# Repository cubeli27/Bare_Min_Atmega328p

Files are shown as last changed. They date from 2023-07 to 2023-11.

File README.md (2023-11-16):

# Bare_Min_Atmega328p
PCB designed for available in-house parts. With my main goal to test the procces of ordering from a fab house, see the outcome, as well as lab capabilities with relatively tiny components, and USB to UART.

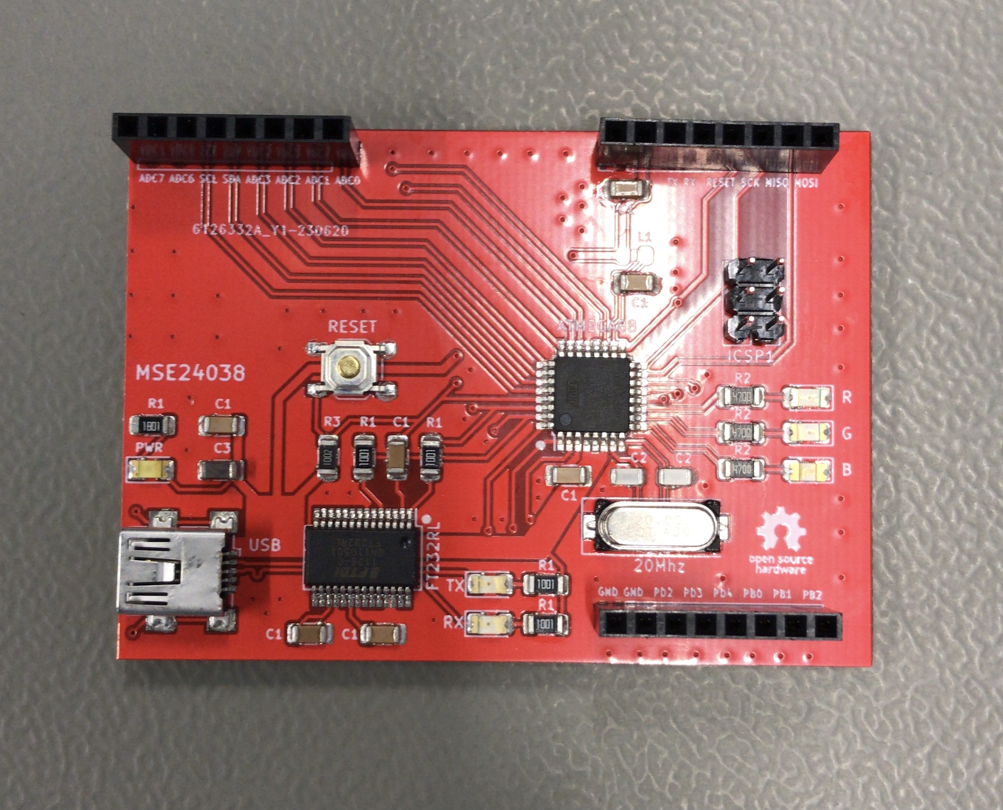
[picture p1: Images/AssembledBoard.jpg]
Assembled Board


# Assembly

Silkscreen is simplified for hand assembly hence the minimum amount of different values and the same names for many parts;
 ```ignore
 | Resistor |  Capacitor   | Inductor    |    LED                  |
 |----------|--------------|-------------|-------------------------|
 | R1 = 1k  | C1 = 100nF   |  L1 = 10uH  | PWR = White             |
 | R2 = 470 | C2 = 22pF    |             | R/G/B = Red/Green/Blue  |
 | R3 = 10k | C3 = 10uF    |             | RX/TX = Orange          |

 ```

Tip: 
R1 next to the PWR led should be more than 1k unless you want it to always be too bright, I recommend 1k8 or 2k2.

# Programming
1. Open in Arduino IDE File/Examples/11.ArduinoISP/ArduinoISP.
2. Uncomment line 81 (// #define USE_OLD_STYLE_WIRING).

UncommentLine

3. Upload the code to your Arduino Uno with Board: Arduino Uno, Programmer: AVRISP mkII.
4. Connect Arduino Uno with the custom board like so:
 ```ignore
 | Uno      |  Custom Board| 
 |----------|--------------|
 | 10       | RESET        |  
 | 11       | MOSI         | 
 | 12       | MISO         |  
 | 13       | SCK          |
 | 5v       | 5v           |
 | GND      | GND          |
 ```
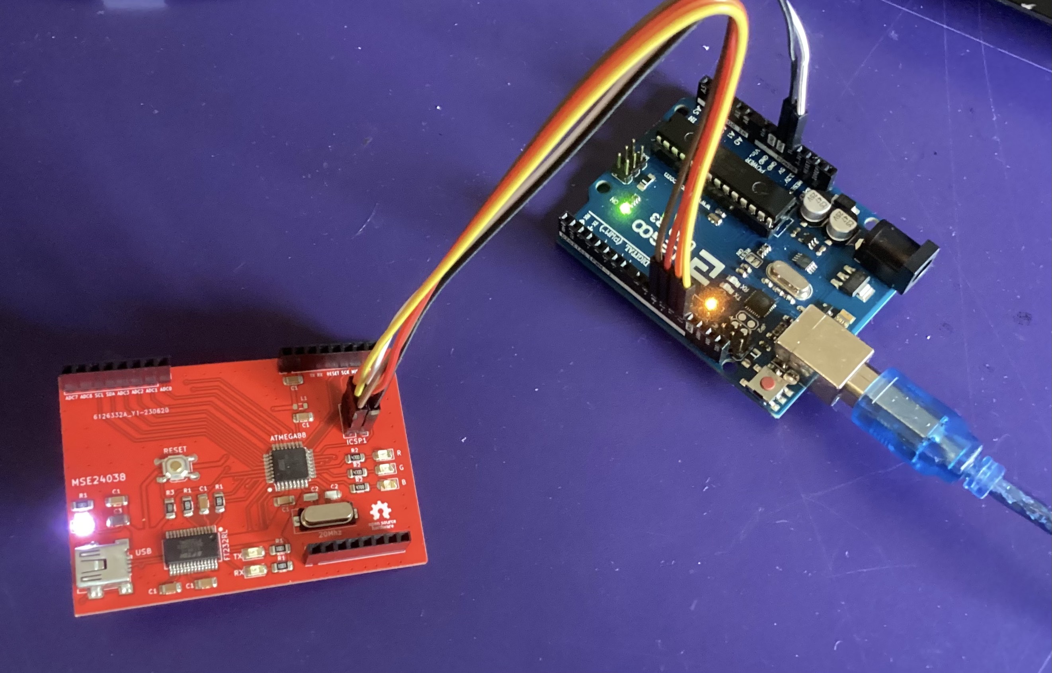
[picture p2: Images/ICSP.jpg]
ICSP


5. Burning the bootloader steps. In Tools set Board: Arduino Duemilanove or Diecimila, Programmer: Arduino as ISP, then click Burn Bootloader.

6. You should see "Done Burning Bootloader". Now you're set and can unplug your jumper wires and store your Arduino Uno you won't need it anymore.

DoneBurningBootloader

7. Connect your custom board to your PC through a USB cable.
8. In order to upload any code just select in Tools Board: Arduino Duemilanove or Diecimila, Programmer: AVRISP mkII, and click Upload (arrow pointing right). You should see the orange LEDs flashing.
9. If you want to start with the blink sketch make sure to use pins 5,6 or 7 because built-in LED's are on those pins.
 ```ignore
 | PIN      |  LED        | 
 |----------|-------------|
 | PD7      | RED         |  
 | PD6      | GREEN       | 
 | PD5      | BLUE        |  
 ```

# *Disclaimer*

This board has no defined purpose it was made for testing the ordering process, the lab assembly capabilities, and USB to UART. 
Additionally, it was designed for the preexisting available components that were lying around the lab. Hence the part selection is suboptimal.
And looking back the design also isn't great, but this being the first board I ever ordered externally I'm super happy with the results and with what I learned.

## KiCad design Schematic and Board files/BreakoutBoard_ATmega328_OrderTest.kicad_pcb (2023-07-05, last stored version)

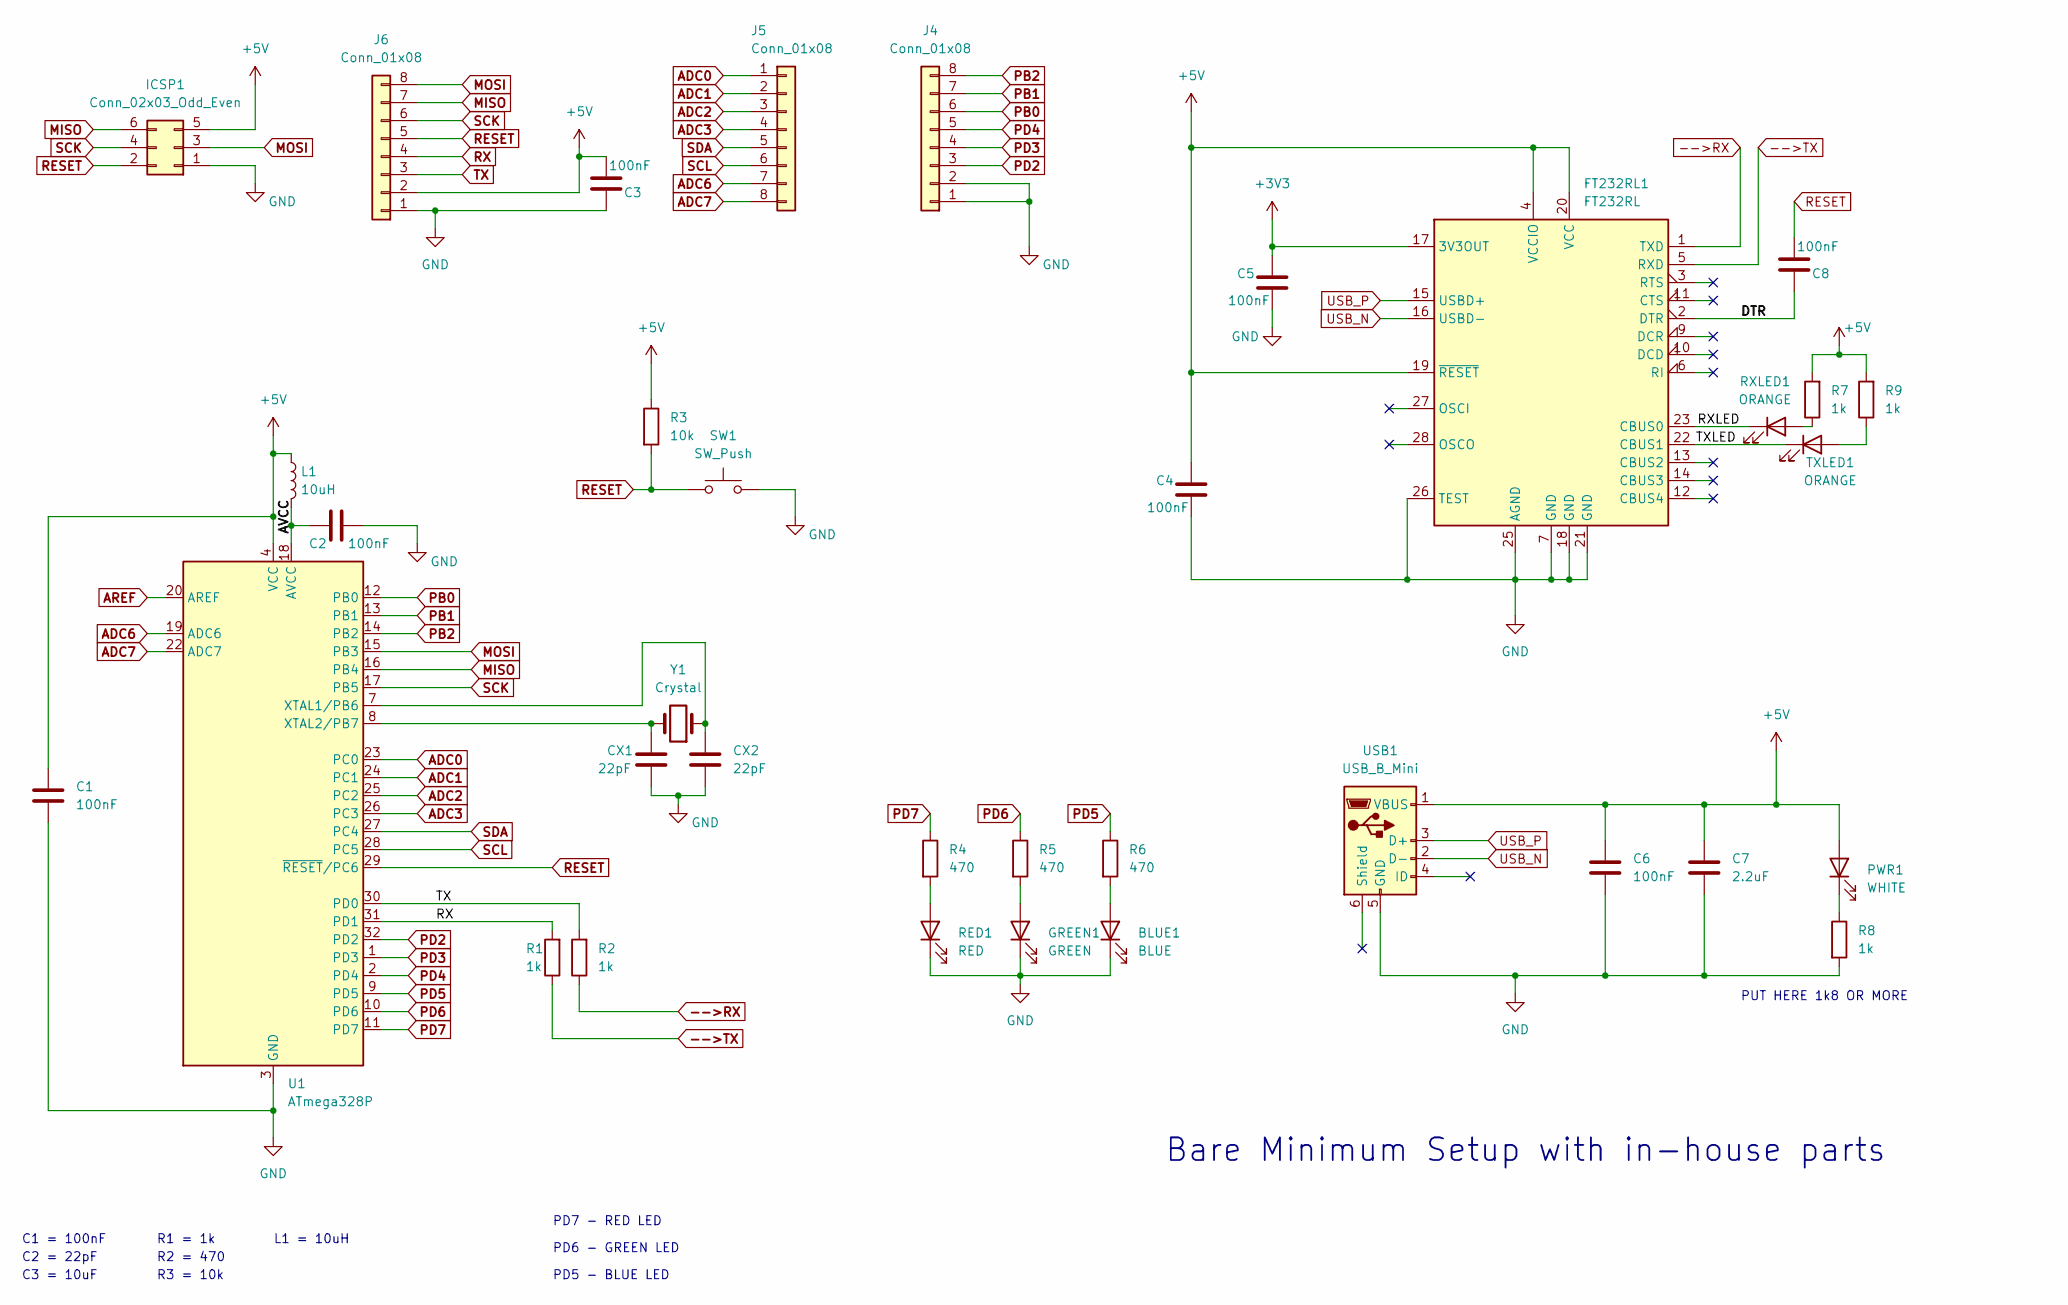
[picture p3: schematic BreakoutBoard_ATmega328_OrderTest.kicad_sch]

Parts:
BLUE1: BLUE; LED_1206_3216Metric
C1, C2, C3, C4, C5, C6, C8: 100nF; C_1206_3216Metric
C7: 2.2uF; C_1206_3216Metric
CX1, CX2: 22pF; C_0805_2012Metric
FT232RL1: FT232RL; SSOP-28_5.3x10.2mm_P0.65mm
GREEN1: GREEN; LED_1206_3216Metric
ICSP1: Conn_02x03_Odd_Even; PinHeader_2x03_P2.54mm_Vertical
J4, J5, J6: Conn_01x08
L1: 10uH; L_0805_2012Metric
PWR1: WHITE; LED_1206_3216Metric
R1, R2, R7, R8, R9: 1k; R_1206_3216Metric
R3: 10k; R_1206_3216Metric
R4, R5, R6: 470; R_1206_3216Metric
RED1: RED; LED_1206_3216Metric
RXLED1: ORANGE; LED_1206_3216Metric
SW1: SW_Push; SW_SPST_TL3342
TXLED1: ORANGE; LED_1206_3216Metric
U1: ATmega328P; TQFP-32_7x7mm_P0.8mm
USB1: USB_B_Mini; USB_Mini-B_Wuerth_65100516121_Horizontal
Y1: Crystal; Crystal_SMD_HC49-SD

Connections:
+3V3: C5.1, FT232RL1.17 (3V3OUT)
+5V: C1.1, C3.2, C4.1, C6.1, C7.1, FT232RL1.4 (VCCIO), FT232RL1.19 (~RESET), FT232RL1.20 (VCC), ICSP1.5, J6.2, L1.1, PWR1.2 (A), R3.1, R7.2, R9.2, U1.4 (VCC), U1.6 (VCC), USB1.1 (VBUS); also elsewhere on the board
-->RX: FT232RL1.1 (TXD), R2.1
-->TX: FT232RL1.5 (RXD), R1.1
/AVCC: C2.1, L1.2, U1.18 (AVCC)
/DTR: C8.1, FT232RL1.2 (DTR)
/RXLED: FT232RL1.23 (CBUS0), RXLED1.1 (K)
/TXLED: FT232RL1.22 (CBUS1), TXLED1.1 (K)
ADC0: J5.1, U1.23 (PC0); also elsewhere on the board
ADC1: J5.2, U1.24 (PC1); also elsewhere on the board
ADC2: J5.3, U1.25 (PC2); also elsewhere on the board
ADC3: J5.4, U1.26 (PC3); also elsewhere on the board
ADC6: J5.7, U1.19 (ADC6); also elsewhere on the board
ADC7: J5.8, U1.22 (ADC7); also elsewhere on the board
AREF: U1.20 (AREF)
GND: BLUE1.1 (K), C1.2, C2.2, C3.1, C4.2, C5.2, C6.2, C7.2, CX1.2, CX2.2, FT232RL1.7 (GND), FT232RL1.18 (GND), FT232RL1.21 (GND), FT232RL1.25 (AGND), FT232RL1.26 (TEST), GREEN1.1 (K), ICSP1.1, J4.1, J4.2, J6.1, R8.2, RED1.1 (K), SW1.2, U1.3 (GND), U1.5 (GND), U1.21 (GND), USB1.5 (GND); also elsewhere on the board
MISO: ICSP1.6, J6.7, U1.16 (PB4); also elsewhere on the board
MOSI: ICSP1.3, J6.8, U1.15 (PB3); also elsewhere on the board
unnamed: BLUE1.2 (A), R6.2
unnamed: GREEN1.2 (A), R5.2
unnamed: PWR1.1 (K), R8.1
unnamed: R4.2, RED1.2 (A)
unnamed: R7.1, RXLED1.2 (A)
unnamed: R9.1, TXLED1.2 (A)
unnamed: CX2.1, U1.7 (XTAL1/PB6), Y1.1
unnamed: CX1.1, U1.8 (XTAL2/PB7), Y1.2
PB0: J4.6, U1.12 (PB0); also elsewhere on the board
PB1: J4.7, U1.13 (PB1); also elsewhere on the board
PB2: J4.8, U1.14 (PB2); also elsewhere on the board
PD2: J4.3, U1.32 (PD2); also elsewhere on the board
PD3: J4.4, U1.1 (PD3); also elsewhere on the board
PD4: J4.5, U1.2 (PD4); also elsewhere on the board
PD5: R6.1, U1.9 (PD5)
PD6: R5.1, U1.10 (PD6)
PD7: R4.1, U1.11 (PD7)
RESET: C8.2, ICSP1.2, J6.5, R3.2, SW1.1, U1.29 (~RESET/PC6); also elsewhere on the board
RX: R1.2, U1.31 (PD1); also elsewhere on the board
SCK: ICSP1.4, J6.6, U1.17 (PB5); also elsewhere on the board
SCL: J5.6, U1.28 (PC5); also elsewhere on the board
SDA: J5.5, U1.27 (PC4); also elsewhere on the board
TX: R2.2, U1.30 (PD0); also elsewhere on the board
USB_N: FT232RL1.16 (USBD-), USB1.2 (D-)
USB_P: FT232RL1.15 (USBD+), USB1.3 (D+)

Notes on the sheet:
R2 = 470
C3 = 10uF
PUT HERE 1k8 OR MORE
C1 = 100nF
R1 = 1k
PD5 - BLUE LED
PD6 - GREEN LED
C2 = 22pF
Bare Minimum Setup with in-house parts
R3 = 10k
PD7 - RED LED
L1 = 10uH

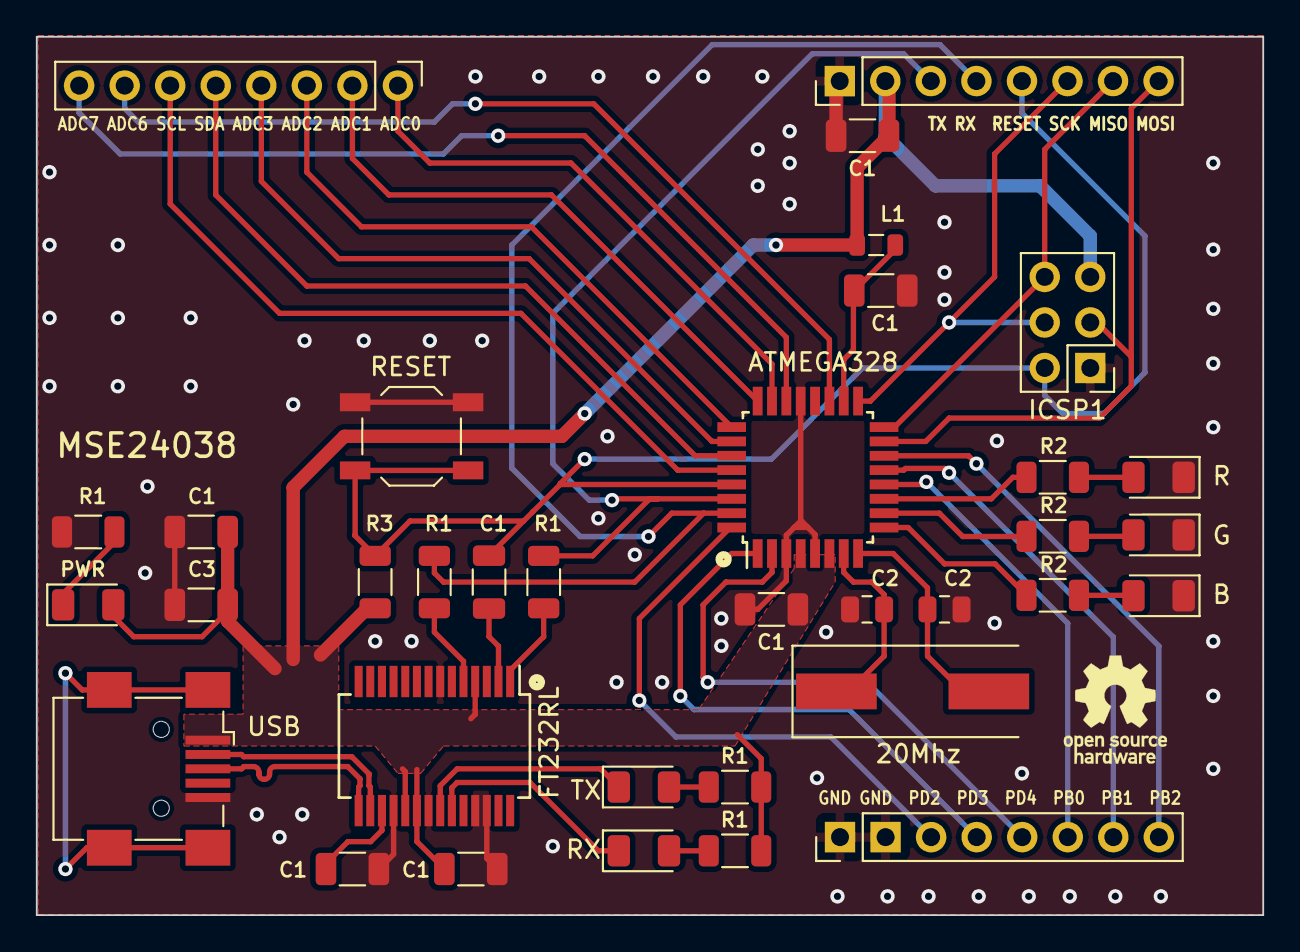
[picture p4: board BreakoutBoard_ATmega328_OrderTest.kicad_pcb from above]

Board: 2 copper layers, 68.4 x 49.0 mm, 35 parts (0 on the bottom side), 42 nets.

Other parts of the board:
J1, J2, J3: Conn_01x08_Socket; PinHeader_1x08_P2.54mm_Vertical

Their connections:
+5V: J1.2; also elsewhere on the board
ADC0: J2.1; also elsewhere on the board
ADC1: J2.2; also elsewhere on the board
ADC2: J2.3; also elsewhere on the board
ADC3: J2.4; also elsewhere on the board
ADC6: J2.7; also elsewhere on the board
ADC7: J2.8; also elsewhere on the board
GND: J1.1, J3.1, J3.2; also elsewhere on the board
MISO: J1.7; also elsewhere on the board
MOSI: J1.8; also elsewhere on the board
PB0: J3.6; also elsewhere on the board
PB1: J3.7; also elsewhere on the board
PB2: J3.8; also elsewhere on the board
PD2: J3.3; also elsewhere on the board
PD3: J3.4; also elsewhere on the board
PD4: J3.5; also elsewhere on the board
RESET: J1.5; also elsewhere on the board
RX: J1.4; also elsewhere on the board
SCK: J1.6; also elsewhere on the board
SCL: J2.6; also elsewhere on the board
SDA: J2.5; also elsewhere on the board
TX: J1.3; also elsewhere on the board
